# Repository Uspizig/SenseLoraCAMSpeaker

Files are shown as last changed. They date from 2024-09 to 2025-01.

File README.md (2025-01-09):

# SenseLoRaCAMSpeaker: The Programmable Addon Board for Xiao Sense S3 for LoRa and Audio

<p align="center"> 
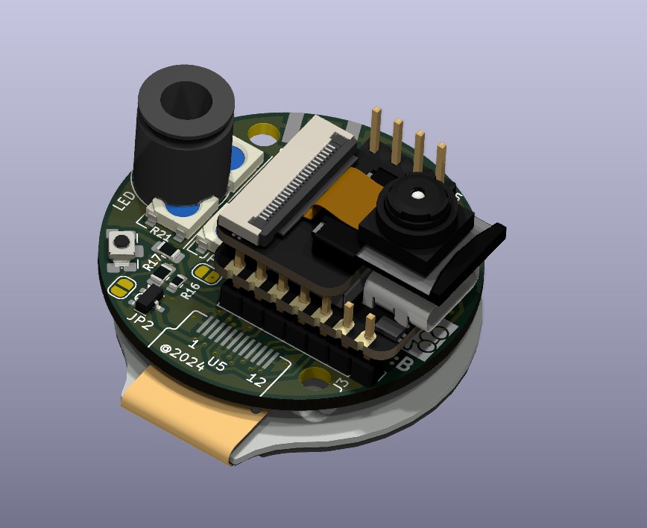
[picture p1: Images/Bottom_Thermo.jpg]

</p>

## Features:

1. **AudioAmplifier MAX98357**: Listen to your favourite Tunes with an Audio Amplifier

2. **I2C Connector for Sensor**: Connect your favourite I2C Sensor board with the embedded 2.54mm connector

3. **LoRa**: Long Range Communication like Meshtastikm, The Thingsnetwork or Helium

4. **Wireless Control**: Untehther your development process with the wireless capabilities. With WiFi, Lora and BLE, this tool allows remote control and data logging. Users can adjust settings and monitor data from a distance, offering a more flexible development experience.

5. **Open Source & Programmable**: As an open-source device, the Device offers unmatched versatility. It is fully programmable, allowing you to tailor its functionality to your specific applications. This customization extends to software and hardware, opening up endless possibilities for creative and efficient project development.

6. **Compact Design**: Designed for convenience, the LoRaCam Board compact and sleek form factor allows for seamless integration into existing setups. Its compatibility with USB PD power sources and inline integration capability minimizes the need for additional equipment or extensive redesign, making it a versatile and user-friendly addition to any development environment.

7. **Display**: Monitor live the current status

<p align="center">
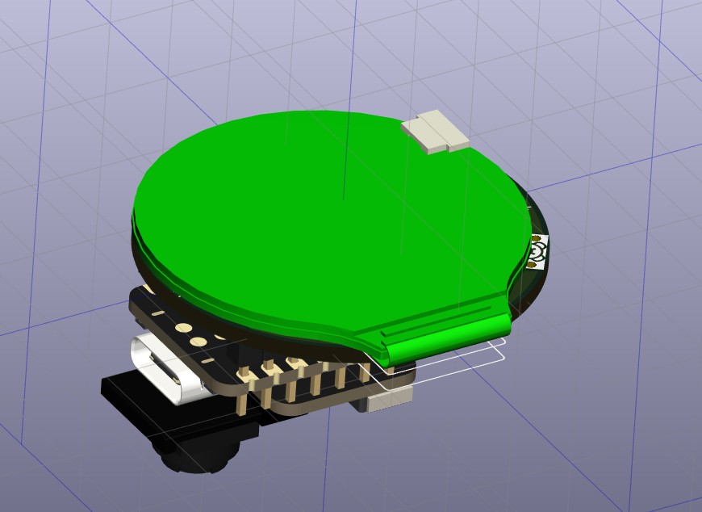
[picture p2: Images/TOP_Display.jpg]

</p>

8. **LoRa**: Operate the Device in remote areas without Wifi in Standalone mode

9. **RGB LED**: Status LED
## Specifications

<p align="center">
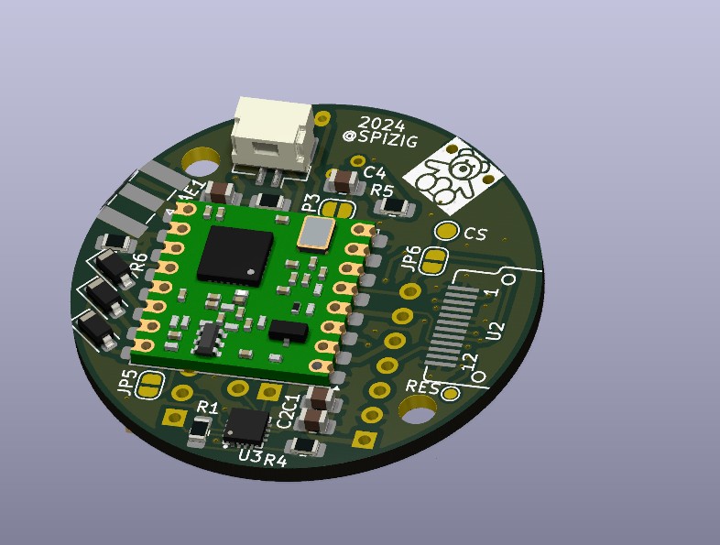
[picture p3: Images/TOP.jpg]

</p>

<p align="center">
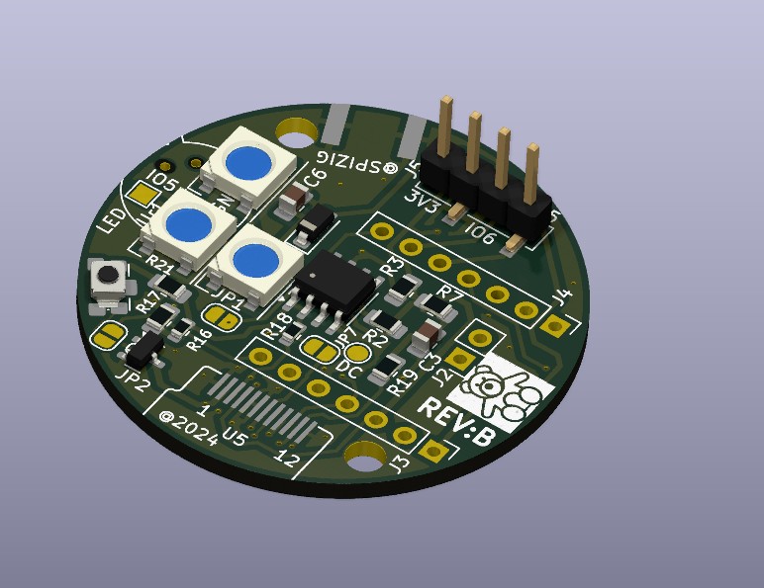
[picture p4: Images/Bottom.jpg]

</p>

### Key Features:

### Future Developments:

AI Detection of objects and determine if the device shall sent the data via LoRa 

## Testing for Performance

At the heart of SenseLoRaCam's design is a commitment to reliability and performance. To ensure that SenseLoRaCam stands up to real-world demands, we subjected it to testing under use conditions.

## License

MIT License

Copyright (c) 2025 blue2monster

Permission is hereby granted, free of charge, to any person obtaining a copy
of this software and associated documentation files (the "Software"), to deal
in the Software without restriction, including without limitation the rights
to use, copy, modify, merge, publish, distribute, sublicense, and/or sell
copies of the Software, and to permit persons to whom the Software is
furnished to do so, subject to the following conditions:

The above copyright notice and this permission notice shall be included in all
copies or substantial portions of the Software.

THE SOFTWARE IS PROVIDED "AS IS", WITHOUT WARRANTY OF ANY KIND, EXPRESS OR
IMPLIED, INCLUDING BUT NOT LIMITED TO THE WARRANTIES OF MERCHANTABILITY,
FITNESS FOR A PARTICULAR PURPOSE AND NONINFRINGEMENT. IN NO EVENT SHALL THE
AUTHORS OR COPYRIGHT HOLDERS BE LIABLE FOR ANY CLAIM, DAMAGES OR OTHER
LIABILITY, WHETHER IN AN ACTION OF CONTRACT, TORT OR OTHERWISE, ARISING FROM,
OUT OF OR IN CONNECTION WITH THE SOFTWARE OR THE USE OR OTHER DEALINGS IN THE
SOFTWARE.

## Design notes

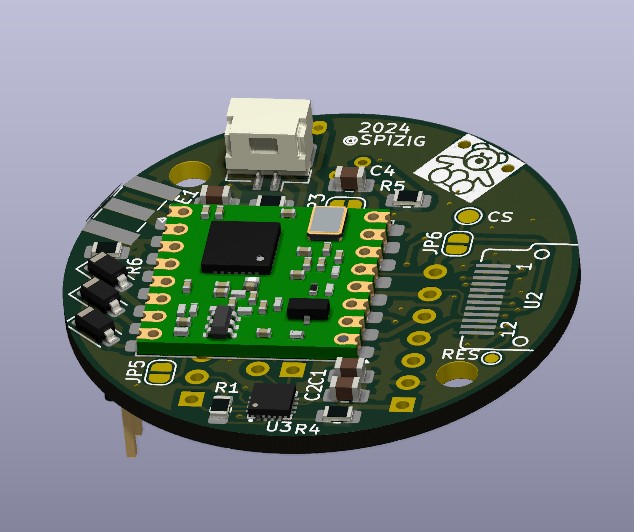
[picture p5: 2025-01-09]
Images/TOP2.jpg

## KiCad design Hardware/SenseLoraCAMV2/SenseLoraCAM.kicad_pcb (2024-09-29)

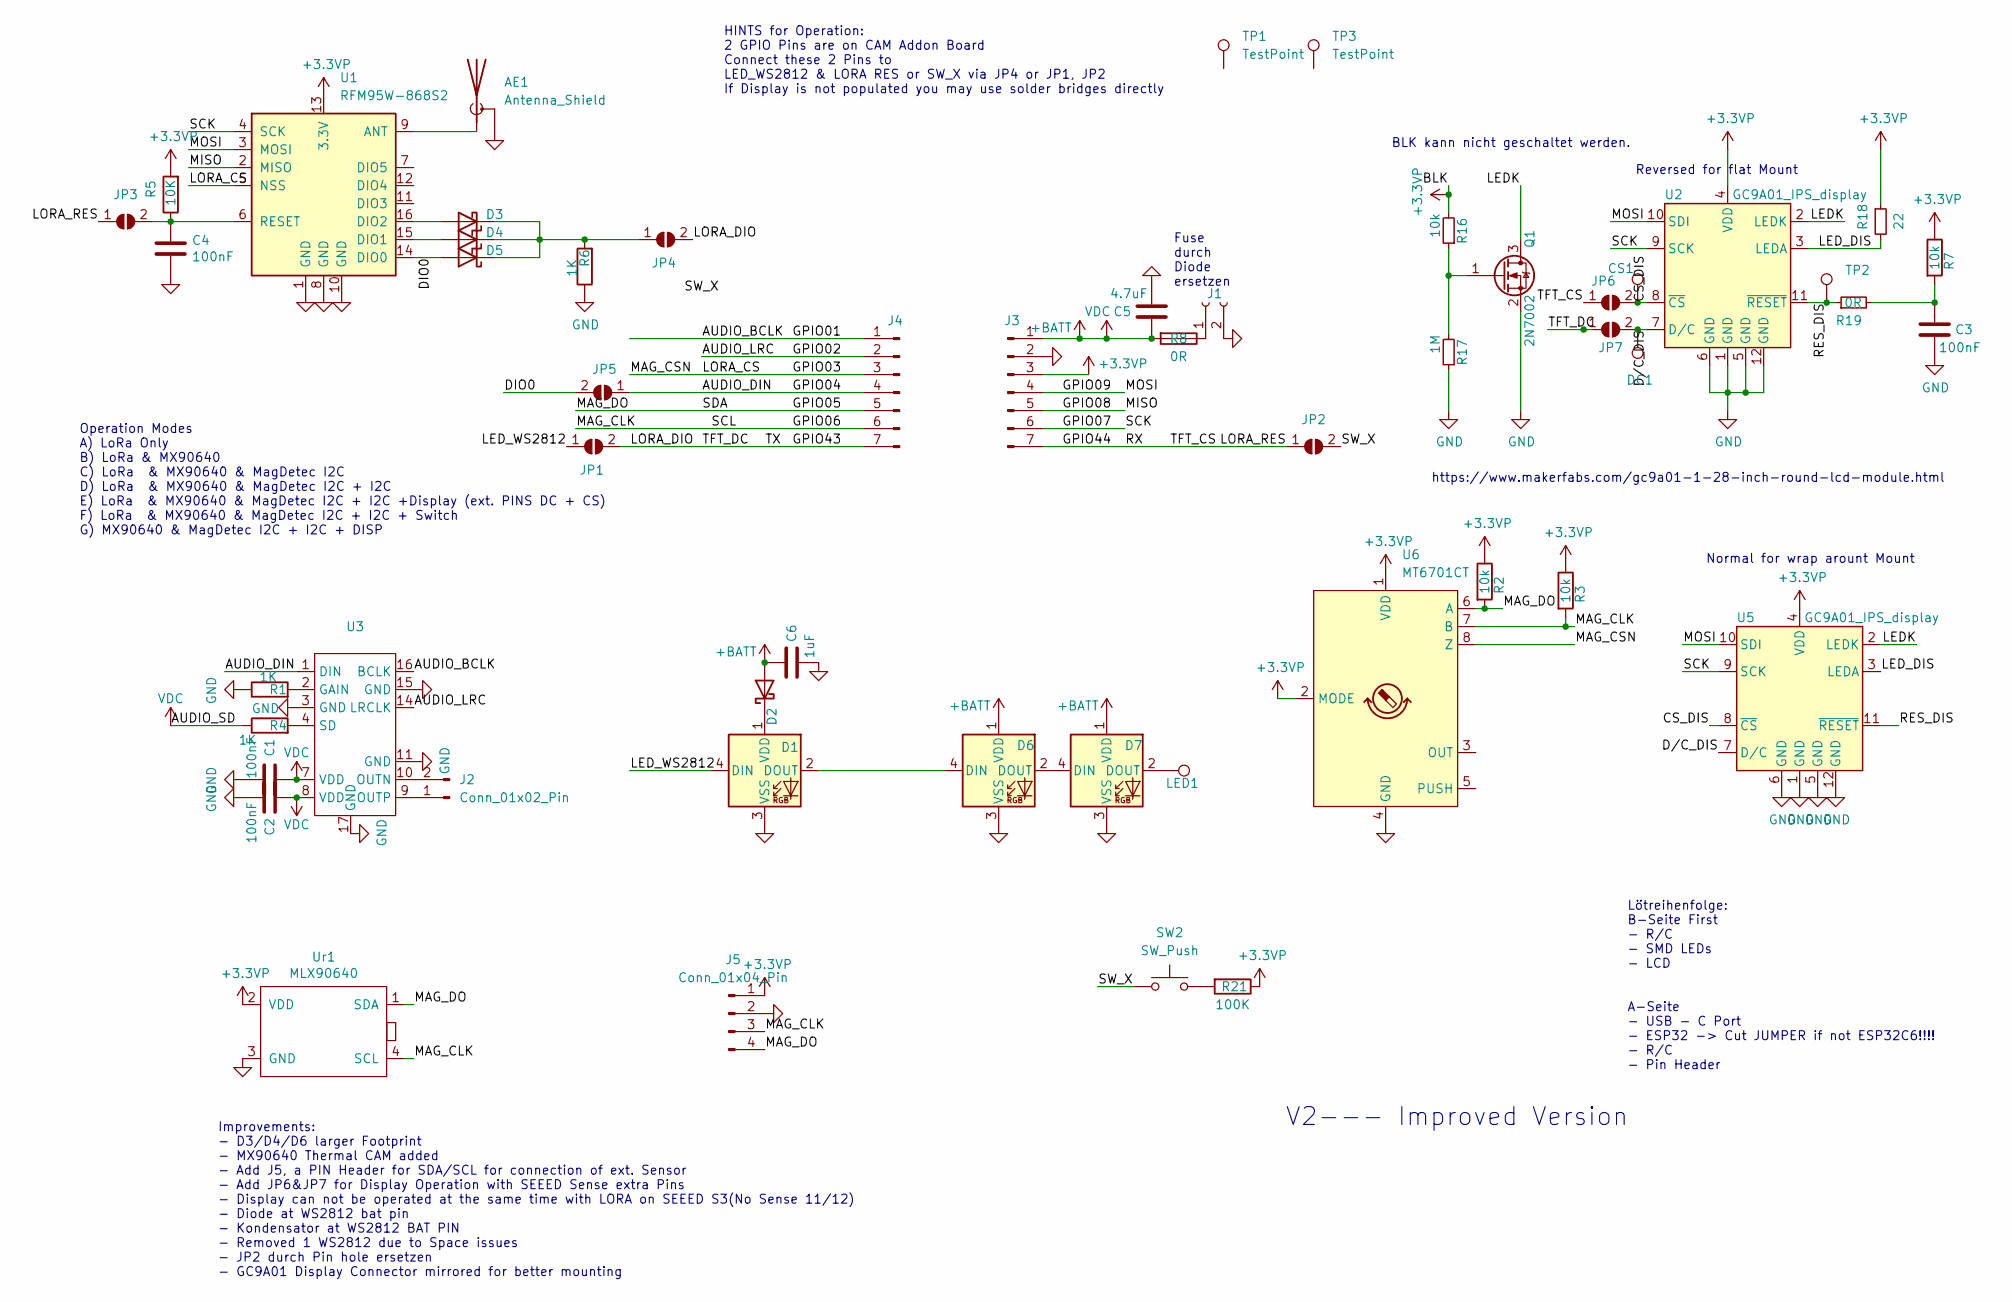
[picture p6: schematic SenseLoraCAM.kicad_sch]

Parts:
AE1: Antenna_Shield; SMA_Samtec_SMA-J-P-X-ST-EM1_EdgeMount
C1, C2, C3, C4: 100nF; C_0805_2012Metric_Pad1.18x1.45mm_HandSolder
C5: 4.7uF; C_0805_2012Metric_Pad1.18x1.45mm_HandSolder
C6: 1uF; C_0805_2012Metric_Pad1.18x1.45mm_HandSolder
CS1: TestPoint; TestPoint_Pad_D1.5mm
D1, D6, D7: WS2812B; LED_WS2812B_PLCC4_5.0x5.0mm_P3.2mm
D2, D3, D4, D5: MBR0530; D_SOD-123
DC1: TestPoint; TestPoint_Pad_D1.5mm
J1: Conn_01x02_Female; JST_GH_SM02B-GHS-TB_1x02-1MP_P1.25mm_Horizontal
J2: Conn_01x02_Pin; PinHeader_1x02_P2.54mm_Vertical
J3, J4: Conn_01x07_Pin; PinHeader_1x07_P2.54mm_Vertical
J5: Conn_01x04_Pin; PinHeader_1x04_P2.54mm_Vertical_SMD_Pin1Right
JP1, JP2, JP3, JP5, JP6, JP7: SolderJumper_2_Open; SolderJumper-2_P1.3mm_Open_RoundedPad1.0x1.5mm
JP4: SolderJumper_2_Open; SolderJumper-2_P1.3mm_Bridged_RoundedPad1.0x1.5mm
LED1: TestPoint; TestPoint_Pad_1.5x1.5mm
Q1: 2N7002; SOT-23
R1, R4, R6: 1K; R_0805_2012Metric_Pad1.20x1.40mm_HandSolder
R2, R3, R7: 10k; R_0805_2012Metric_Pad1.20x1.40mm_HandSolder
R5: 10K; R_0805_2012Metric_Pad1.20x1.40mm_HandSolder
R8, R19: 0R; R_0805_2012Metric_Pad1.20x1.40mm_HandSolder
R16: 10k; R_0603_1608Metric
R17: 1M; R_0805_2012Metric_Pad1.20x1.40mm_HandSolder
R18: 22; R_0603_1608Metric
R21: 100K; R_0805_2012Metric_Pad1.20x1.40mm_HandSolder
SW2: SW_Push; SW_SPST_CK_KMS2xxGP
TP1, TP3: TestPoint; baerklein
TP2: TestPoint; TestPoint_Pad_D1.0mm
U1: RFM95W-868S2; HOPERF_RFM9XW_SMD
U2: GC9A01_IPS_display; GC9A01_IPS_display_reversed
U3: TQFN-16_L3.0-W3.0-P0.50-BL-EP1.5
U5: GC9A01_IPS_display
U6: MT6701CT; SO-8_3.9x4.9mm_P1.27mm
Ur1: MLX90640; Part Number 482-MLX90640ESFBABSP

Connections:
+3.3VP: J3.3, J5.1, R2.1, R3.1, R5.2, R7.1, R16.2, R18.1, R21.1, U1.13 (3.3V), U2.4 (VDD), U5.4 (VDD), U6.1 (VDD), U6.2 (MODE), Ur1.2 (VDD)
+BATT: C1.1, C2.1, C5.1, C6.1, D2.2 (A), D6.1 (VDD), D7.1 (VDD), J3.1, R4.1, R8.2, U3.7 (VDD), U3.8 (VDD)
/AUDIO_BCLK: J4.1, U3.16 (BCLK)
/AUDIO_DIN: J4.4, JP5.1 (A), U3.1 (DIN)
/AUDIO_LRC: J4.2, U3.14 (LRCLK)
/CS_DIS: CS1.1, JP6.2 (B), U2.8 (~CS), U5.8 (~CS); also elsewhere on the board
/DIO0: D5.2 (A), JP5.2 (B), U1.14 (DIO0)
/D/C_DIS: DC1.1, JP7.2 (B), U2.7 (D/C), U5.7 (D/C); also elsewhere on the board
/GPIO03: J4.3, U1.5 (NSS), U6.8 (Z)
/GPIO05: J4.5, J5.4, R2.2, U6.6 (A), Ur1.1 (SDA)
/GPIO06: J4.6, J5.3, R3.2, U6.7 (B), Ur1.4 (SCL)
/GPIO07: J3.6, U1.4 (SCK), U2.9 (SCK), U5.9 (SCK)
/GPIO08: J3.5, U1.2 (MISO)
/GPIO09: J3.4, U1.3 (MOSI), U2.10 (SDI), U5.10 (SDI)
/GPIO43: J4.7, JP1.2 (B), JP4.2 (B), JP7.1 (A)
/GPIO44: J3.7, JP2.1 (A), JP3.1 (A), JP6.1 (A)
/LEDK: Q1.3 (D), U2.2 (LEDK), U5.2 (LEDK)
/LED_DIS: R18.2, U2.3 (LEDA), U5.3 (LEDA)
/LED_WS2812: D1.4 (DIN), JP1.1 (A)
/RES_DIS: R19.1, TP2.1, U2.11 (~RESET), U5.11 (~RESET); also elsewhere on the board
/SW_X: JP2.2 (B), SW2.2
GND: AE1.2 (Shield), C1.2, C2.2, C3.2, C4.1, C5.2, C6.2, D1.3 (VSS), D6.3 (VSS), D7.3 (VSS), J1.2, J3.2, J5.2, Q1.2 (S), R1.1, R6.1, R17.1, U1.1 (GND), U1.8 (GND), U1.10 (GND), U2.1 (GND), U2.5 (GND), U2.6 (GND), U2.12 (GND), U3.3 (GND), U3.11 (GND), U3.15 (GND), U3.17 (GND), U5.1 (GND), U5.5 (GND), U5.6 (GND), U5.12 (GND), U6.4 (GND), Ur1.3 (GND)
unnamed: AE1.1 (A), U1.9 (ANT)
unnamed: C3.1, R7.2, R19.2
unnamed: D1.2 (DOUT), D6.4 (DIN)
unnamed: D1.1 (VDD), D2.1 (K)
unnamed: D3.2 (A), U1.16 (DIO2)
unnamed: D3.1 (K), D4.1 (K), D5.1 (K), JP4.1 (A), R6.2
unnamed: D4.2 (A), U1.15 (DIO1)
unnamed: D6.2 (DOUT), D7.4 (DIN)
unnamed 30: D7.2 (DOUT), LED1.1; also elsewhere on the board
unnamed: J1.1, R8.1
unnamed: J2.1, U3.9 (OUTP)
unnamed: J2.2, U3.10 (OUTN)
unnamed: C4.2, JP3.2 (B), R5.1, U1.6 (RESET)
unnamed: Q1.1 (G), R16.1, R17.2
unnamed: R21.2, SW2.1
unnamed: R1.2, U3.2 (GAIN)
unnamed: R4.2, U3.4 (SD)

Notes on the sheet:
Lötreihenfolge: B-Seite First - R/C - SMD LEDs - LCD A-Seite - USB - C Port - ESP32 -> Cut JUMPER if not ESP32C6!!!! - R/C - Pin Header
HINTS for Operation: 2 GPIO Pins are on CAM Addon Board Connect these 2 Pins to LED_WS2812 & LORA RES or SW_X via JP4 or JP1, JP2 If Display is not populated you may use solder bridges directly
Normal for wrap arount Mount
https://www.makerfabs.com/gc9a01-1-28-inch-round-lcd-module.html
V2--- Improved Version
Reversed for flat Mount
Fuse durch Diode ersetzen
Operation Modes A) LoRa Only B) LoRa & MX90640 C) LoRa & MX90640 & MagDetec I2C D) LoRa & MX90640 & MagDetec I2C + I2C E) LoRa & MX90640 & MagDetec I2C + I2C +Display (ext. PINS DC + CS) F) LoRa & MX90640 & MagDetec I2C + I2C + Switch G) MX90640 & MagDetec I2C + I2C + DISP
BLK kann nicht geschaltet werden.
Improvements: - D3/D4/D6 larger Footprint - MX90640 Thermal CAM added - Add J5, a PIN Header for SDA/SCL for connection of ext. Sensor - Add JP6&JP7 for Display Operation with SEEED Sense extra Pins - Display can not be operated at the same time with LORA on SEEED S3(No Sense 11/12) - Diode at WS28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

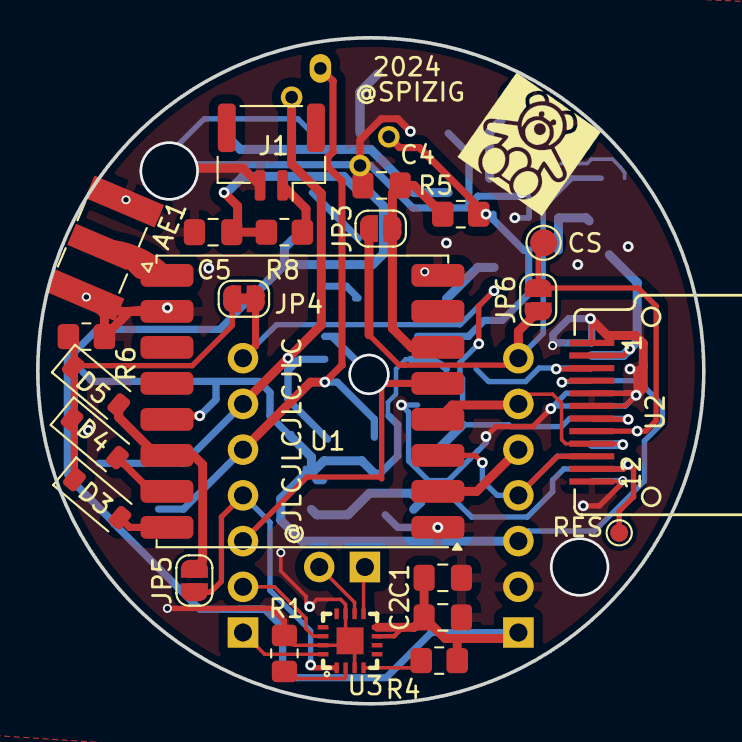
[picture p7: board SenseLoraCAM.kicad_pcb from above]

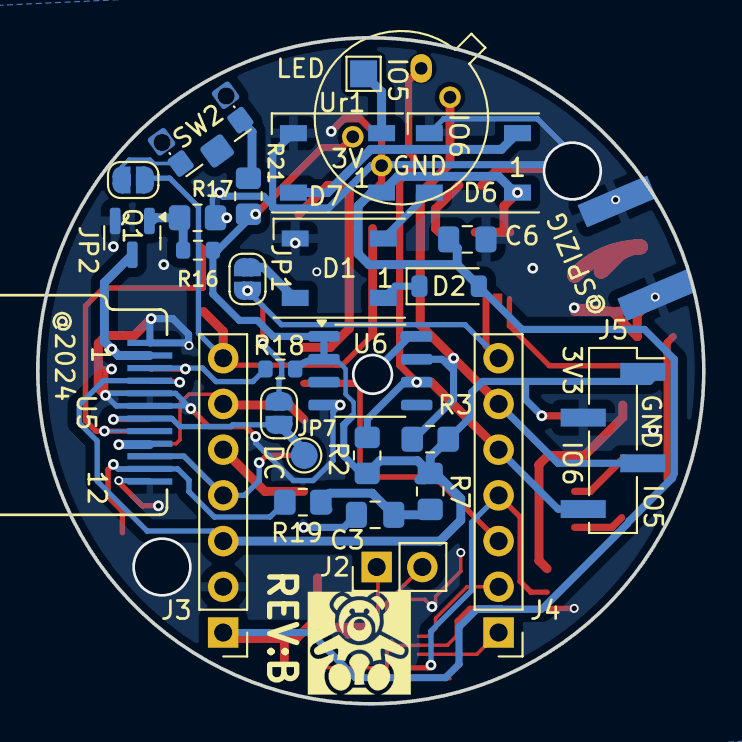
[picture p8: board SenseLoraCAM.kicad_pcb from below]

Board: 2 copper layers, 37.0 x 37.0 mm, 53 parts (29 on the bottom side), 39 nets.

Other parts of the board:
CS: TestPoint; TestPoint_Pad_D1.5mm
DC: TestPoint; TestPoint_Pad_D1.5mm
LED: TestPoint; TestPoint_Pad_1.5x1.5mm
RES: TestPoint; TestPoint_Pad_D1.0mm

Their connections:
/CS_DIS: CS.1; also elsewhere on the board
/D/C_DIS: DC.1; also elsewhere on the board
/RES_DIS: RES.1; also elsewhere on the board
unnamed 30: LED.1; also elsewhere on the board

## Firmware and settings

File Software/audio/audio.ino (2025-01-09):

#include "Arduino.h"
#include "WiFi.h"
#include "Audio.h"
#include "SD.h"
#include "FS.h"
#include "USB.h"
#include <Adafruit_NeoPixel.h>

// Digital I/O used
#define SD_CS         21
#define SPI_MOSI      9
#define SPI_MISO      8
#define SPI_SCK       7
#define I2S_DOUT      4
#define I2S_BCLK      1
#define I2S_LRC       2
#define BUTTON        6
#define PIN_LMIC_NSS  3

#define PIN        43//2 // On Trinket or Gemma, suggest changing this to 1  PIN 2 bei Platine V1 PIN 43 bei JP1 gebrückt
#define NUMPIXELS 1 // Popular NeoPixel ring size
Adafruit_NeoPixel pixels(NUMPIXELS, PIN, NEO_GRB + NEO_KHZ800);
#define DELAYVAL 500 // Time (in milliseconds) to pause between pixels

Audio audio;
USBCDC USBSerial;
String ssid =     "xxxxxx";
String password = "xxxxx";
String hostname = "ESP32 Node Temperature";

int buttonState = 0;  // variable for reading the pushbutton status

void setup() {
    delay(2000); 
    USBSerial.begin(115200);USB.begin();
    delay(2000); 
    USBSerial.println("BOOT UP");
    pinMode(BUTTON, INPUT_PULLDOWN);
  
  
    pinMode(PIN_LMIC_NSS, OUTPUT); digitalWrite(PIN_LMIC_NSS, HIGH); // sonst startet der Kartenleser nicht. Irgendwas blockiert da auf dem SPI BUS
    pinMode(SD_CS, OUTPUT);      digitalWrite(SD_CS, HIGH);
    SPI.begin(SPI_SCK, SPI_MISO, SPI_MOSI);
    
    SD.begin(SD_CS);
    USBSerial.println("SD BEGIN");
    WiFi.disconnect();
    delay(2000); 
    WiFi.mode(WIFI_STA);
    delay(2000); 
    WiFi.config(INADDR_NONE, INADDR_NONE, INADDR_NONE, INADDR_NONE);
    //WiFi.setHostname(hostname.c_str()); //define hostname
    WiFi.begin(ssid.c_str(), password.c_str());
    USBSerial.println("WIFI START");
    //while (WiFi.status() != WL_CONNECTED){USBSerial.println("."); delay(1500);} 
    audio.setPinout(I2S_BCLK, I2S_LRC, I2S_DOUT);
    audio.setVolume(8); // default 0...21
    pixels.begin(); // INITIALIZE NeoPixel strip object (REQUIRED)
    pixels.clear(); // Set all pixel colors to 'off'
    for(int i=0; i<NUMPIXELS; i++) { // For each pixel...
        // pixels.Color() takes RGB values, from 0,0,0 up to 255,255,255
        // Here we're using a moderately bright green color:
        pixels.setPixelColor(i, pixels.Color(0, 10, 0));
        pixels.show();   // Send the updated pixel colors to the hardware.
        delay(DELAYVAL); // Pause before next pass through loop
        USBSerial.println("Booting");
  }
  USBSerial.println("LEDON");
//  or alternative
//  audio.setVolumeSteps(64); // max 255
//  audio.setVolume(63);    
//
//  *** radio streams ***
//    audio.connecttohost("http://stream.antennethueringen.de/live/aac-64/stream.antennethueringen.de/"); // aac
//  audio.connecttohost("http://mcrscast.mcr.iol.pt/cidadefm");                                         // mp3
//  audio.connecttohost("http://www.wdr.de/wdrlive/media/einslive.m3u");                                // m3u
//  audio.connecttohost("https://stream.srg-ssr.ch/rsp/aacp_48.asx");                                   // asx
//  audio.connecttohost("http://tuner.classical102.com/listen.pls");                                    // pls
//  audio.connecttohost("http://stream.radioparadise.com/flac");                                        // flac
//  audio.connecttohost("http://stream.sing-sing-bis.org:8000/singsingFlac");                           // flac (ogg)
//  audio.connecttohost("http://s1.knixx.fm:5347/dein_webradio_vbr.opus");                              // opus (ogg)
//  audio.connecttohost("http://stream2.dancewave.online:8080/dance.ogg");                              // vorbis (ogg)
//  audio.connecttohost("http://26373.live.streamtheworld.com:3690/XHQQ_FMAAC/HLSTS/playlist.m3u8");    // HLS
//  audio.connecttohost("http://eldoradolive02.akamaized.net/hls/live/2043453/eldorado/master.m3u8");   // HLS (ts)
//  *** web files ***
//  audio.connecttohost("https://github.com/schreibfaul1/ESP32-audioI2S/raw/master/additional_info/Testfiles/Pink-Panther.wav");        // wav
//  audio.connecttohost("https://github.com/schreibfaul1/ESP32-audioI2S/raw/master/additional_info/Testfiles/Santiano-Wellerman.flac"); // flac
//  audio.connecttohost("https://github.com/schreibfaul1/ESP32-audioI2S/raw/master/additional_info/Testfiles/Olsen-Banden.mp3");        // mp3
//  audio.connecttohost("https://github.com/schreibfaul1/ESP32-audioI2S/raw/master/additional_info/Testfiles/Miss-Marple.m4a");         // m4a (aac)
//  audio.connecttohost("https://github.com/schreibfaul1/ESP32-audioI2S/raw/master/additional_info/Testfiles/Collide.ogg");             // vorbis
//  audio.connecttohost("https://github.com/schreibfaul1/ESP32-audioI2S/raw/master/additional_info/Testfiles/sample.opus");             // opus
//  *** local files ***
  audio.connecttoFS(SD, "/test4.wav");     // SD //RICHTIG
//  audio.connecttoFS(SD_MMC, "/test4.wav"); // SD_MMC //FALSCH
//  audio.connecttoFS(SPIFFS, "/test.wav"); // SPIFFS

//  audio.connecttospeech("Wenn die Hunde schlafen, kann der Wolf gut Schafe stehlen.", "de"); // Google TTS
USBSerial.print("AudioActive");
}

void loop()
{
    audio.loop();
    buttonState = digitalRead(BUTTON);

  // check if the pushbutton is pressed. If it is, the buttonState is HIGH:
  if (buttonState == HIGH) {
    // turn LED BLUE:
    pixels.setPixelColor(0, pixels.Color(0, 0, 10));
  } else {
    // turn LED RED:
    pixels.setPixelColor(0, pixels.Color(10, 0, 0));
  }
  pixels.show();   // Send the updated pixel colors to the hardware.
}

// optional
void audio_info(const char *info){
    USBSerial.print("info        "); USBSerial.println(info);
}
void audio_id3data(const char *info){  //id3 metadata
    USBSerial.print("id3data     ");USBSerial.println(info);
}
void audio_eof_mp3(const char *info){  //end of file
    USBSerial.print("eof_mp3     ");USBSerial.println(info);
}
void audio_showstation(const char *info){
    USBSerial.print("station     ");USBSerial.println(info);
}
void audio_showstreamtitle(const char *info){
    USBSerial.print("streamtitle ");USBSerial.println(info);
}
void audio_bitrate(const char *info){
    USBSerial.print("bitrate     ");USBSerial.println(info);
}
void audio_commercial(const char *info){  //duration in sec
    USBSerial.print("commercial  ");USBSerial.println(info);
}
void audio_icyurl(const char *info){  //homepage
    USBSerial.print("icyurl      ");USBSerial.println(info);
}
void audio_lasthost(const char *info){  //stream URL played
    USBSerial.print("lasthost    ");USBSerial.println(info);
}
void audio_eof_speech(const char *info){
    USBSerial.print("eof_speech  ");USBSerial.println(info);
}

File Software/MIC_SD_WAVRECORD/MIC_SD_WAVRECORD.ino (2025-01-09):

/* Ungetestet...vllt I2s Port 1 nehmen statt 0
FUNKTIONIERT NICHT MALLOC FAILED i2S Driver install error

 https://forum.seeedstudio.com/t/xiao-esp32s3-sense-arduino-i2s-mic-init-question/271251/3
 * DI2S Version, 
 * WAV Recorder for Seeed XIAO ESP32S3 Sense
 * 
 * Original: https://wiki.seeedstudio.com/xiao_esp32s3_sense_mic/
 */

#include "driver/i2s.h"
#include "Arduino.h"
#include "WiFi.h"
#include "Audio.h"
#include "FS.h"
#include "SD.h"
#include "SPI.h"
#include "USB.h"

// make changes as needed
#define RECORD_TIME   20  // seconds, The maximum value is 240
#define WAV_FILE_NAME "arduino_rec_DI2S"
#define I2S_DOUT      4
#define I2S_BCLK      1
#define I2S_LRC       2
#define MIC_CLK       42
#define MIC_DAT       41
#define PIN_LMIC_NSS  3
#define SD_CS         21

// do not change for best
#define SAMPLE_RATE 16000U
#define SAMPLE_BITS 16
#define WAV_HEADER_SIZE 44
#define VOLUME_GAIN 2


Audio audio;
USBCDC USBSerial;

String ssid =     "wallyweb2";
String password = "FS4burgberg";

void setup() {
  
  pinMode(PIN_LMIC_NSS, OUTPUT); digitalWrite(PIN_LMIC_NSS, HIGH); // sonst startet der Kartenleser nicht. Irgendwas blockiert da auf dem SPI BUS
  pinMode(SD_CS, OUTPUT);      digitalWrite(SD_CS, HIGH);
  
  USBSerial.begin(115200);USB.begin();
  //Serial.begin(115200);
  delay(2000); 
  WiFi.disconnect();
  WiFi.mode(WIFI_STA);
  WiFi.begin(ssid.c_str(), password.c_str());
  //while (WiFi.status() != WL_CONNECTED){USBSerial.println("."); delay(1500);} 

  i2s_init();
  
  if(!SD.begin(SD_CS)){
    USBSerial.println("Failed to mount SD Card!");
    while (1) ;
  }
  record_wav();
  audio_setup();
  //i2s_deinit();
  

}

void loop() {
  audio.loop();
  delay(1000);
  USBSerial.printf(".");
}

void record_wav() {
  //delay(2000); 
  
  size_t  sample_size = 0;
  //uint32_t sample_size = 0;
  uint32_t record_size = (SAMPLE_RATE * SAMPLE_BITS / 8) * RECORD_TIME;
  uint8_t *rec_buffer = NULL;
  USBSerial.printf("Ready to start recording ...\n");

  File file = SD.open("/"WAV_FILE_NAME".wav", FILE_WRITE);
  // Write the header to the WAV file
  uint8_t wav_header[WAV_HEADER_SIZE];
  generate_wav_header(wav_header, record_size, SAMPLE_RATE);
  file.write(wav_header, WAV_HEADER_SIZE);

  // PSRAM malloc for recording
  rec_buffer = (uint8_t *)ps_malloc(record_size);
  if (rec_buffer == NULL) {
    USBSerial.printf("malloc failed!\n");
    while(1) ;
  }
  USBSerial.printf("Buffer: %d bytes\n", ESP.getPsramSize() - ESP.getFreePsram());

  // Start recording
  i2s_read((i2s_port_t)0, (void*)rec_buffer, record_size, &sample_size, portMAX_DELAY);
  
  if (sample_size == 0) {
    USBSerial.printf("Record Failed!\n");
  } else {
    USBSerial.printf("Record %d bytes\n", sample_size);
  }

  // Increase volume
  for (uint32_t i = 0; i < sample_size; i += SAMPLE_BITS/8) {
    (*(uint16_t *)(rec_buffer+i)) <<= VOLUME_GAIN;
  }

  // Write data to the WAV file
  USBSerial.printf("Writing to the file ...\n");
  if (file.write(rec_buffer, record_size) != record_size)
    USBSerial.printf("Write file Failed!\n");

  free(rec_buffer);
  file.close();
  USBSerial.printf("The recording is over.\n");
}

void generate_wav_header(uint8_t *wav_header, uint32_t wav_size, uint32_t sample_rate) {
  // See this for reference: http://soundfile.sapp.org/doc/WaveFormat/
  uint32_t file_size = wav_size + WAV_HEADER_SIZE - 8;
  uint32_t byte_rate = SAMPLE_RATE * SAMPLE_BITS / 8;
  const uint8_t set_wav_header[] = {
    'R', 'I', 'F', 'F', // ChunkID
    file_size, file_size >> 8, file_size >> 16, file_size >> 24, // ChunkSize
    'W', 'A', 'V', 'E', // Format
    'f', 'm', 't', ' ', // Subchunk1ID
    0x10, 0x00, 0x00, 0x00, // Subchunk1Size (16 for PCM)
    0x01, 0x00, // AudioFormat (1 for PCM)
    0x01, 0x00, // NumChannels (1 channel)
    sample_rate, sample_rate >> 8, sample_rate >> 16, sample_rate >> 24, // SampleRate
    byte_rate, byte_rate >> 8, byte_rate >> 16, byte_rate >> 24, // ByteRate
    0x02, 0x00, // BlockAlign
    0x10, 0x00, // BitsPerSample (16 bits)
    'd', 'a', 't', 'a', // Subchunk2ID
    wav_size, wav_size >> 8, wav_size >> 16, wav_size >> 24, // Subchunk2Size
  };
  memcpy(wav_header, set_wav_header, sizeof(set_wav_header));
}

static int i2s_init() {
  // Start listening for audio: MONO @ 16/16KHz
  i2s_config_t i2s_config = {
    .mode                 = (i2s_mode_t)(I2S_MODE_MASTER | I2S_MODE_RX | I2S_MODE_PDM ),
    .sample_rate          = 16000U,
    .bits_per_sample      = I2S_BITS_PER_SAMPLE_16BIT,
    //.channel_format       = I2S_CHANNEL_FMT_ONLY_RIGHT,     // Also works
    .channel_format       = I2S_CHANNEL_FMT_ONLY_LEFT,
    //.communication_format = I2S_COMM_FORMAT_PCM,            // Also works
    .communication_format = I2S_COMM_FORMAT_I2S,   
    .intr_alloc_flags     = ESP_INTR_FLAG_LEVEL1,
    .dma_buf_count        = 8,
    .dma_buf_len          = 512,    
    .use_apll             = false,
    .tx_desc_auto_clear   = false,
    .fixed_mclk           = 0
  };
  
  i2s_pin_config_t pin_config = {
      .bck_io_num = -1,    // IIS_SCLK
      .ws_io_num = MIC_CLK,     // IIS_LCLK
      .data_out_num = -1,  // IIS_DSIN
      .data_in_num = MIC_DAT,   // IIS_DOUT
  
  };
  esp_err_t ret = 0;

  ret = i2s_driver_install((i2s_port_t)0, &i2s_config, 0, NULL);
  if (ret != ESP_OK) {
    USBSerial.printf("Error in i2s_driver_install");
  }

  ret = i2s_set_pin((i2s_port_t)0, &pin_config);
  if (ret != ESP_OK) {
    USBSerial.printf("Error in i2s_set_pin");
  }

  ret = i2s_zero_dma_buffer((i2s_port_t)0);
  if (ret != ESP_OK) {
    USBSerial.printf("Error in initializing dma buffer with 0");
  }

  return int(ret);
}

static int i2s_deinit(void) {
    i2s_driver_uninstall((i2s_port_t)0); //stop & destroy i2s driver
    return 0;
}


void audio_setup(void){
	audio.setPinout(I2S_BCLK, I2S_LRC, I2S_DOUT);
	audio.setVolume(8); // default 0...21
}
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
